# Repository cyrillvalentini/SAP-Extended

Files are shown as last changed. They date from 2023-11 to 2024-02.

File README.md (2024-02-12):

# SAP-Extended
Simple-As-Possible Computer based on [Ben Eaters video series](https://www.youtube.com/watch?v=HyznrdDSSGM&list=PLowKtXNTBypGqImE405J2565dvjafglHU&pp=iAQB).
## Project
As part of my matura project, I planned and build an 8-Bit computer based around the design from Ben Eater. This repository contains the schematics, design files and instructions for the computer.
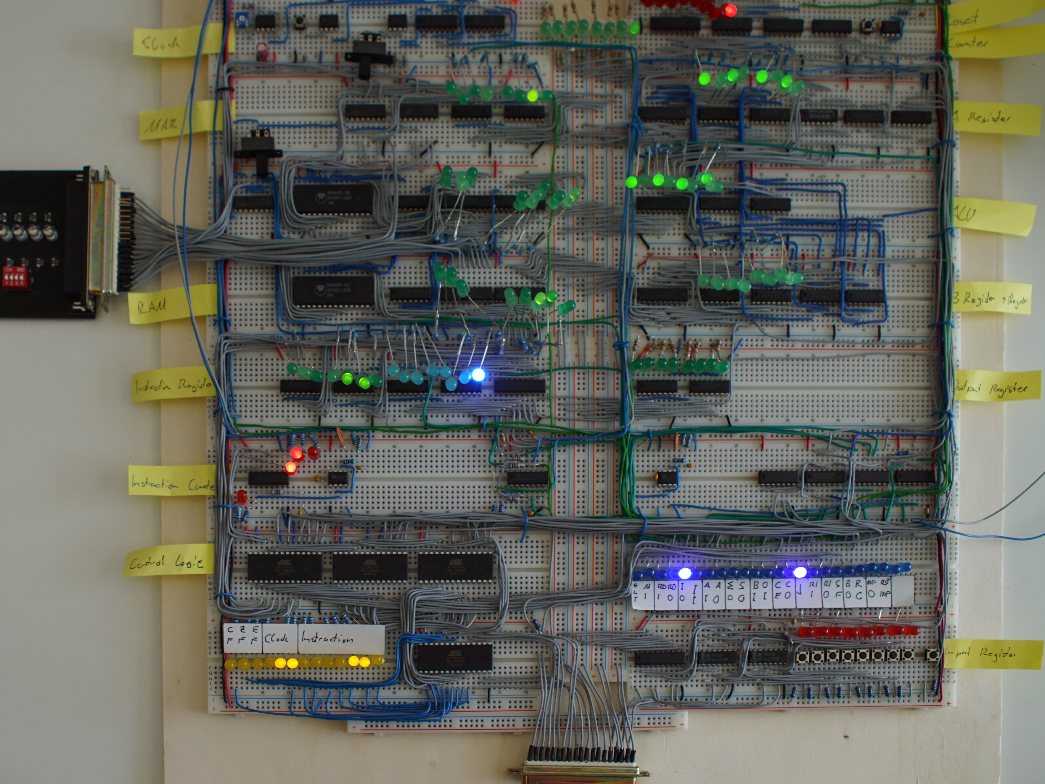
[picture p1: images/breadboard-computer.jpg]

## Breadboard-computer
The breadboard variant is heavily inspired by the computer made by Ben Eater. In the first phase I build computer, which is functionally similar to his design, while occasionally using different parts which were either already on hand or made the process of expanding easier in the future. After a successful test run, I started to expand the design. To allow for longer programs I expanded the RAM to allow 8-Bit addresses and 7-Bit instructions. This allows for a maximum length of 256 instructions. In order to make these changes different modules had to be expanded as well. The other major difference is the expansion port, which allows expansion cards to be created for the computer. The signals are handled by an additional EEPROM-chip within the control logic.

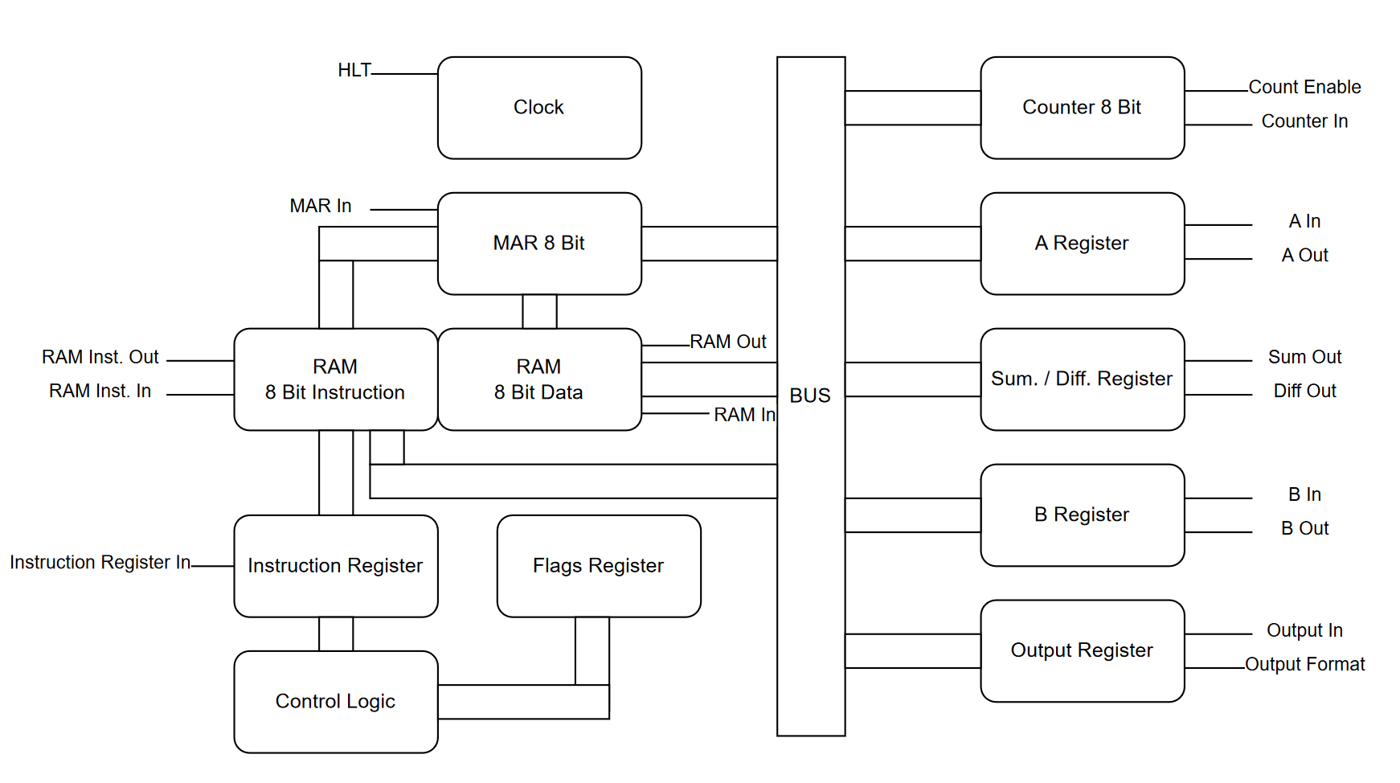
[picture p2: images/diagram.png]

*Simplified diagram of the changes made to the architecture.* 

## Schematics and PCB
After building the breadboard variant, I started working on a PCB version. Being the first larger design, there are some power related issues and some missing filtering components which prevent the computer from running completely. In addition to the breadboard version this design includes a 7-segment display as well as additional power input options. There is an integrated buck converter and an USB Type C port which can supply 5V 3A using PD.

The schematics and PCB were created using KiCad 7.

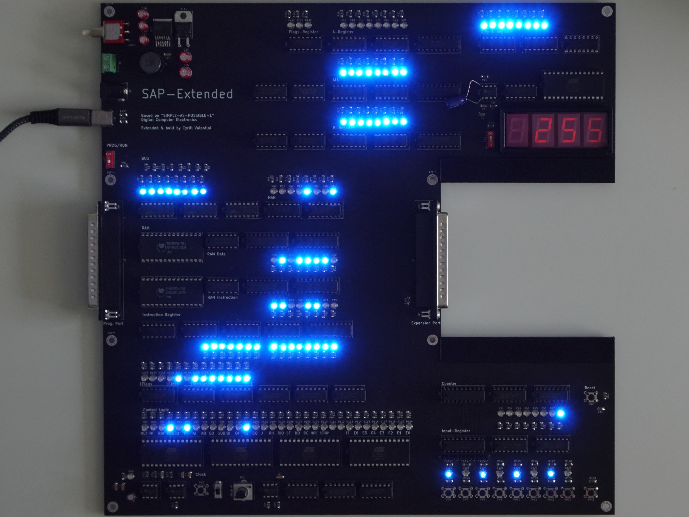
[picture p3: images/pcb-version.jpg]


## Usage
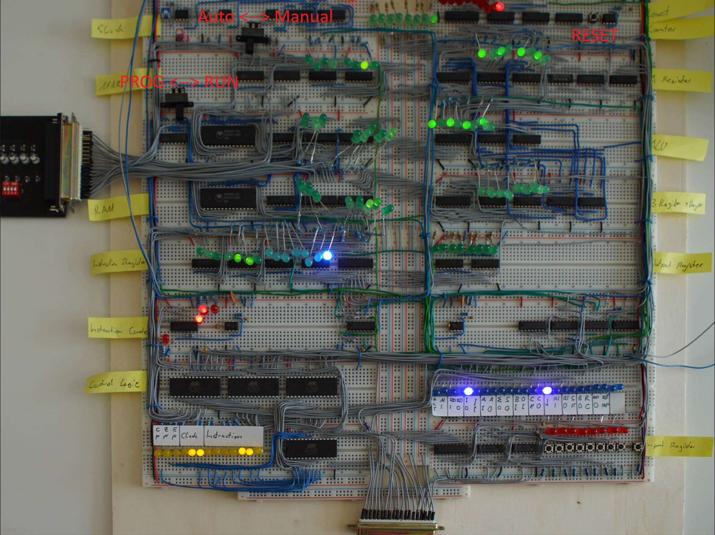
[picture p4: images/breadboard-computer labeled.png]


### Programming the computer
To set the computer to programming mode, the clock switch must first be set to manual. The LED should then stop flashing. It is then advisable to press the RESET button once to clear all registers. To be able to program the computer, the programmer must also be plugged in and the RUN/PROGRAM switch must be set to PROGRAM.

Now the actual programming can begin. First, the desired address must be set; without jump commands, these are iterated through in ascending order. In this case, the first command can be saved in the address 00000001. This is followed by the actual command, which can also be entered using the DIP switches. Finally, if the command requires it, the address to be accessed by the command can be entered under "DATA". Once the entire command has been typed in, the "FLASH" button can be pressed. The command should then be displayed in RAM. It is important that the address 00000000 is empty and is not used, as the computer does not always read in the first command after resetting.

### Examples
<center>

| RAM-address| adding two numbers | show input in output-register |
|---|---|---|
| 0000 0001  | 0000 0001 0000 1000 (LDA) | 0000 1010 0000 0000 (INA) |
| 0000 0010  | 0000 0011 0001 0000 (ADD) | 0000 0101 0000 0000 (OUT) |
| 0000 0011  | 0000 0101 0000 0000 (OUT) | 0000 0110 0000 0001 (JMP) |
| 0000 0100  | 0000 1100 0000 0000 (HLT) | |
| ... | | |
| 0000 0100  | 0000 0000 0000 0011 (3) | |
| ... | | |
| 0000 0100  | 0000 0000 0000 0001 (1) | |

</center>

### Run a program
To start the program, the switch must be set to RUN. As soon as this has been done, the program can be started either manually by using the button or by switching to automatic mode. For the I/O, it should be noted that the switch next to the display can be used to switch the decimal output between unsigned binary and two's complement. In addition, the input register deletes its contents after use or can be deleted manually using the button next to it. The commands can be found [here](https://github.com/cyrillvalentini/SAP-Extended/blob/main/instructions.pdf)
## Microcode
The control logic is build using AT28C64B parallel EEPROMs, which need to be programmed. The binary file was created using the [txt2bin.py](https://github.com/cyrillvalentini/SAP-Extended/blob/main/microcode/txt2bin.py) python script. The microcode can conveniently be changed as a text file and converted back into a binary image.

The microcode can be flashed to the EEPROMs using crmaykish's [Arduino Mega EEPROM programmer](https://github.com/crmaykish/AT28C-EEPROM-Programmer-Arduino). After hooking everything up as described in the documentation, the EEPROMs can be flashed with their corresponding firmware using following command:

`python.exe .\at28c_programmer.py -d <port> -o 0 -f <microcode.bin> -l 8192 -w`

## Programming port
The modular programming interface allows to use different programmers to load the program into RAM. As of now, there is only a manual programmer that can be used, automatic variants are planned. The interface connects the programmer with a set of multiplexer, which can be controlled using the corresponding switch. By switching to programming mode, the RAM-address as well as the data pins are connected with the pins in the port, which can be accessed by the programmer. There is an additional flash-signal which is hooked up to the write input of the RAM-chips. The full specs of the pins can be found [here](https://github.com/cyrillvalentini/SAP-Extended/blob/main/expansions/programming-port%20specification.pdf).

Note that for entering the programming mode successfully the clock must be set to manual in order to function correctly.

## Expansions
To allow for future expansion both versions of the computer have an expansion port controlled by a dedicated EEPROM within the control logic. There are 16 individual instructions present in the microcode, which can be used to interact with the expansion. The full specifications can be found [here](https://github.com/cyrillvalentini/SAP-Extended/blob/main/expansions/expansion-port%20specification.pdf).

### 8x8 LED-matrix
As of now, the LED-matrix expansion is still in a prototyping phase. Once finished this expansion will allow to display simple graphics which can be copied row by row from either the RAM or the A-register. Combined with the input buttons this will allow the development of simple games, which can be run on the computer. 

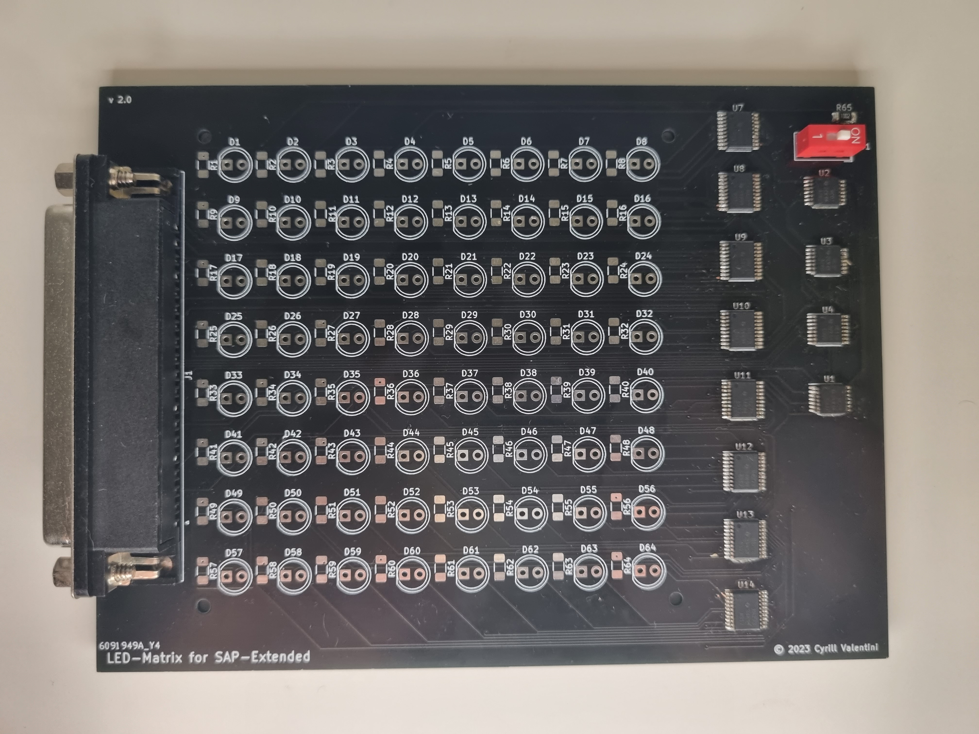
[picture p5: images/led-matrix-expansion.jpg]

*Unfinished prototype of the 8x8 led-matrix*

### Planed expansions
- ALU expansion to allow for additional operations (e.g. logic operations)
- LCD character display
- Automatic programmer

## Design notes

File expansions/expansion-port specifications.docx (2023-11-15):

# Pin allocation expansion-port

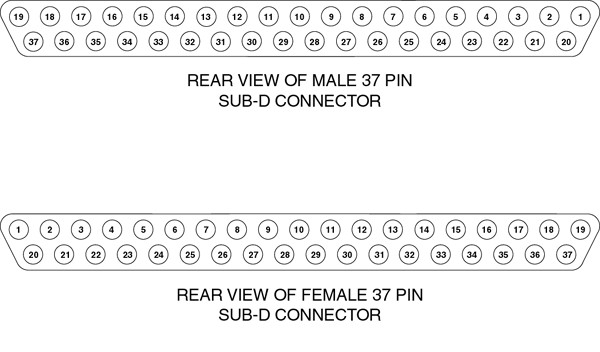
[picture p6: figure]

Image 1 https://forum.dcs.world/topic/184909-a-10c-fmscdu-from-ebay/

Pin: | Allocation: | | Pin: | Allocation
1 | RESET | | 20 | -
2 | FLAG | | 21 | -
3 | CLK | | 22 | -
4 | E7 | | 23 | -
5 | E6 | | 24 | -
6 | E5 | | 25 | -
7 | E4 | | 26 | -
8 | E3 | | 27 | -
9 | E2 | | 28 | -
10 | E1 | | 29 | -
11 | E0 | | 30 | -
12 | BUS7 | | 31 | -
13 | BUS6 | | 32 | -
14 | BUS5 | | 33 | -
15 | BUS4 | | 34 | VCC
16 | BUS3 | | 35 | VCC
17 | BUS2 | | 36 | GND
18 | BUS1 | | 37 | GND
19 | BUS0

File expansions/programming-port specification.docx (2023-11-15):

# Pin allocation programming-port


Image 1 https://forum.dcs.world/topic/184909-a-10c-fmscdu-from-ebay/

Pin: | Allocation: | | Pin: | Allocation:
1 | - | | 20 | RD0
2 | - | | 21 | RD1
3 | - | | 22 | RD2
4 | - | | 23 | RD3
5 | - | | 24 | RD4
6 | - | | 25 | RD5
7 | - | | 26 | RD6
8 | - | | 27 | RD7
9 | - | | 28 | RI0
10 | - | | 29 | RI1
11 | ADR0 | | 30 | RI2
12 | ADR1 | | 31 | RI3
13 | ADR2 | | 32 | RI4
14 | ADR3 | | 33 | RI5
15 | ADR4 | | 34 | RI6
16 | ADR5 | | 35 | RI7
17 | ADR6 | | 36 | WE
18 | ADR7 | | 37 | GND
19 | VCC

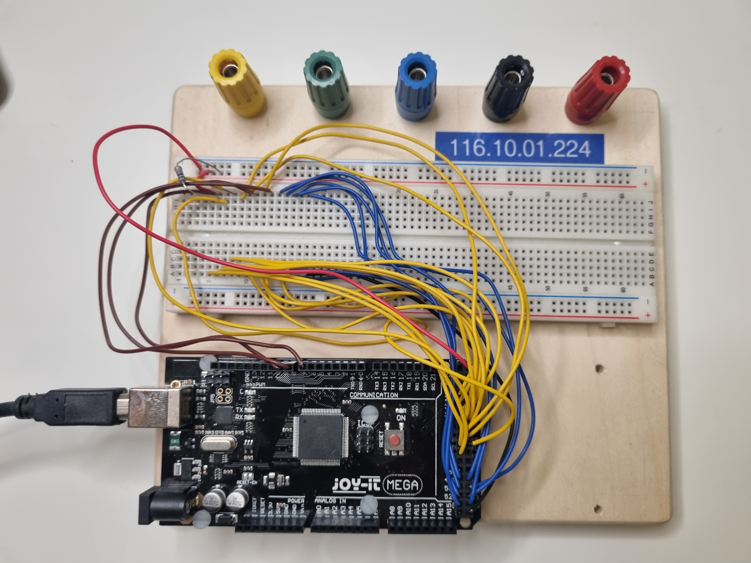
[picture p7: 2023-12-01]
images/arduino-mega-programmer.jpg

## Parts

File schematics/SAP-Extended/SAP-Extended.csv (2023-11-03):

Source: | C:\Users\Cyril\OneDrive - Gymnasium Lerbermatt\MA\SAP-Extended\SAP-Extended\SAP-Extended.kicad_sch
Date: | 19.07.2023 22:45:41
Tool: | Eeschema 7.0.5
Generator: | C:\Program Files\KiCad\7.0\bin\scripting\plugins/bom_csv_grouped_by_value_with_fp.py
Component Count: | 399
Ref | Qnty | Value | Cmp name | Footprint | Description | Vendor | DNP
C1, C2, C16 | 3 | 0.01 uF | C_Small | Capacitor_SMD:C_1206_3216Metric_Pad1.33x1.80mm_HandSolder | Unpolarized capacitor, small symbol
C3, C4, C6 | 3 | 0.1µF | C | Capacitor_SMD:C_1206_3216Metric_Pad1.33x1.80mm_HandSolder | Unpolarized capacitor
C5, C7, C8 | 3 | 0.01µF | C | Capacitor_SMD:C_1206_3216Metric_Pad1.33x1.80mm_HandSolder | Unpolarized capacitor
C9 | 1 | 1µF | CP1-Device | Capacitor_THT:CP_Radial_D5.0mm_P2.00mm
C10, C11, C12 | 3 | 15 µF/50V | C_Polarized_Small | Capacitor_THT:CP_Radial_D5.0mm_P2.00mm | Polarized capacitor, small symbol
C13 | 1 | 0.01 µF | C_Small | Capacitor_SMD:C_1206_3216Metric | Unpolarized capacitor, small symbol
C14 | 1 | 180 µF / 16 V | C_Polarized_Small | Capacitor_THT:CP_Radial_D6.3mm_P2.50mm | Polarized capacitor, small symbol
C15 | 1 | 180 µF/ 16V | C_Polarized_Small | Capacitor_THT:CP_Radial_D6.3mm_P2.50mm | Polarized capacitor, small symbol
D1, D2, D3, D4, D5, D6, D7, D8, D49, D82, D90, D91, D92, D93, D94, D95, D96, D97, D98, D99, D100, D101, D102, D103, D104, D105, D106, D107, D108, D109, D110, D111, D112, D113, D114, D115, D116, D117, D118, D119, D120 | 41 | LED | LED | LED_THT:LED_D3.0mm | Light emitting diode
D9 | 1 | B_0 | LED | LED_THT:LED_D3.0mm | Light emitting diode
D10 | 1 | B_1 | LED | LED_THT:LED_D3.0mm | Light emitting diode
D11 | 1 | B_2 | LED | LED_THT:LED_D3.0mm | Light emitting diode
D12 | 1 | B_3 | LED | LED_THT:LED_D3.0mm | Light emitting diode
D13 | 1 | B_4 | LED | LED_THT:LED_D3.0mm | Light emitting diode
D14 | 1 | B_5 | LED | LED_THT:LED_D3.0mm | Light emitting diode
D15 | 1 | B_6 | LED | LED_THT:LED_D3.0mm | Light emitting diode
D16 | 1 | B_7 | LED | LED_THT:LED_D3.0mm | Light emitting diode
D17 | 1 | A_7 | LED | LED_THT:LED_D3.0mm | Light emitting diode
D18 | 1 | A_6 | LED | LED_THT:LED_D3.0mm | Light emitting diode
D19 | 1 | A_5 | LED | LED_THT:LED_D3.0mm | Light emitting diode
D20 | 1 | A_4 | LED | LED_THT:LED_D3.0mm | Light emitting diode
D21 | 1 | A_3 | LED | LED_THT:LED_D3.0mm | Light emitting diode
D22 | 1 | A_2 | LED | LED_THT:LED_D3.0mm | Light emitting diode
D23 | 1 | A_1 | LED | LED_THT:LED_D3.0mm | Light emitting diode
D24 | 1 | A_0 | LED | LED_THT:LED_D3.0mm | Light emitting diode
D25 | 1 | S_7 | LED | LED_THT:LED_D3.0mm | Light emitting diode
D26 | 1 | S_6 | LED | LED_THT:LED_D3.0mm | Light emitting diode
D27 | 1 | S_5 | LED | LED_THT:LED_D3.0mm | Light emitting diode
D28 | 1 | S_4 | LED | LED_THT:LED_D3.0mm | Light emitting diode
D29 | 1 | S_3 | LED | LED_THT:LED_D3.0mm | Light emitting diode
D30 | 1 | S_2 | LED | LED_THT:LED_D3.0mm | Light emitting diode
D31 | 1 | S_1 | LED | LED_THT:LED_D3.0mm | Light emitting diode
D32 | 1 | S_0 | LED | LED_THT:LED_D3.0mm | Light emitting diode
D33 | 1 | O_7 | LED | LED_THT:LED_D3.0mm | Light emitting diode
D34 | 1 | O_6 | LED | LED_THT:LED_D3.0mm | Light emitting diode
D35 | 1 | O_5 | LED | LED_THT:LED_D3.0mm | Light emitting diode
D36 | 1 | O_4 | LED | LED_THT:LED_D3.0mm | Light emitting diode
D37 | 1 | O_3 | LED | LED_THT:LED_D3.0mm | Light emitting diode
D38 | 1 | O_2 | LED | LED_THT:LED_D3.0mm | Light emitting diode
D39 | 1 | O_1 | LED | LED_THT:LED_D3.0mm | Light emitting diode
D40 | 1 | O_0 | LED | LED_THT:LED_D3.0mm | Light emitting diode
D41 | 1 | C_7 | LED | LED_THT:LED_D3.0mm | Light emitting diode
D42 | 1 | C_6 | LED | LED_THT:LED_D3.0mm | Light emitting diode
D43 | 1 | C_5 | LED | LED_THT:LED_D3.0mm | Light emitting diode
D44 | 1 | C_4 | LED | LED_THT:LED_D3.0mm | Light emitting diode
D45 | 1 | C_3 | LED | LED_THT:LED_D3.0mm | Light emitting diode
D46 | 1 | C_2 | LED | LED_THT:LED_D3.0mm | Light emitting diode
D47 | 1 | C_1 | LED | LED_THT:LED_D3.0mm | Light emitting diode
D48 | 1 | C_0 | LED | LED_THT:LED_D3.0mm | Light emitting diode
D50 | 1 | M_7 | LED | LED_THT:LED_D3.0mm | Light emitting diode
D51 | 1 | M_6 | LED | LED_THT:LED_D3.0mm | Light emitting diode
D52 | 1 | M_5 | LED | LED_THT:LED_D3.0mm | Light emitting diode
D53 | 1 | M_4 | LED | LED_THT:LED_D3.0mm | Light emitting diode
D54 | 1 | M_3 | LED | LED_THT:LED_D3.0mm | Light emitting diode
D55 | 1 | M_2 | LED | LED_THT:LED_D3.0mm | Light emitting diode
D56 | 1 | M_1 | LED | LED_THT:LED_D3.0mm | Light emitting diode
D57 | 1 | M_0 | LED | LED_THT:LED_D3.0mm | Light emitting diode
D58 | 1 | RD_0 | LED | LED_THT:LED_D3.0mm | Light emitting diode
D59 | 1 | RD_1 | LED | LED_THT:LED_D3.0mm | Light emitting diode
D60 | 1 | RD_2 | LED | LED_THT:LED_D3.0mm | Light emitting diode
D61 | 1 | RD_3 | LED | LED_THT:LED_D3.0mm | Light emitting diode
D62 | 1 | RD_4 | LED | LED_THT:LED_D3.0mm | Light emitting diode
D63 | 1 | RD_5 | LED | LED_THT:LED_D3.0mm | Light emitting diode
D64 | 1 | RD_6 | LED | LED_THT:LED_D3.0mm | Light emitting diode
D65 | 1 | RD_7 | LED | LED_THT:LED_D3.0mm | Light emitting diode
D66 | 1 | RI_7 | LED | LED_THT:LED_D3.0mm | Light emitting diode
D67 | 1 | RI_6 | LED | LED_THT:LED_D3.0mm | Light emitting diode
D68 | 1 | RI_5 | LED | LED_THT:LED_D3.0mm | Light emitting diode
D69 | 1 | RI_4 | LED | LED_THT:LED_D3.0mm | Light emitting diode
D70 | 1 | RI_3 | LED | LED_THT:LED_D3.0mm | Light emitting diode
D71 | 1 | RI_2 | LED | LED_THT:LED_D3.0mm | Light emitting diode
D72 | 1 | RI_1 | LED | LED_THT:LED_D3.0mm | Light emitting diode
D73 | 1 | RI_0 | LED | LED_THT:LED_D3.0mm | Light emitting diode
D74 | 1 | IRD_7 | LED | LED_THT:LED_D3.0mm | Light emitting diode
D75 | 1 | IRD_6 | LED | LED_THT:LED_D3.0mm | Light emitting diode
D76 | 1 | IRD_5 | LED | LED_THT:LED_D3.0mm | Light emitting diode
D77 | 1 | IRD_4 | LED | LED_THT:LED_D3.0mm | Light emitting diode
D78 | 1 | IRD_3 | LED | LED_THT:LED_D3.0mm | Light emitting diode
D79 | 1 | IRD_2 | LED | LED_THT:LED_D3.0mm | Light emitting diode
D80 | 1 | IRD_1 | LED | LED_THT:LED_D3.0mm | Light emitting diode
D81 | 1 | IRD_0 | LED | LED_THT:LED_D3.0mm | Light emitting diode
D83 | 1 | IRI_6 | LED | LED_THT:LED_D3.0mm | Light emitting diode
D84 | 1 | IRI_5 | LED | LED_THT:LED_D3.0mm | Light emitting diode
D85 | 1 | IRI_4 | LED | LED_THT:LED_D3.0mm | Light emitting diode
D86 | 1 | IRI_3 | LED | LED_THT:LED_D3.0mm | Light emitting diode
D87 | 1 | IRI_2 | LED | LED_THT:LED_D3.0mm | Light emitting diode
D88 | 1 | IRI_1 | LED | LED_THT:LED_D3.0mm | Light emitting diode
D89 | 1 | IRI_0 | LED | LED_THT:LED_D3.0mm | Light emitting diode
D121 | 1 | STPS745 | D_Schottky | Package_TO_SOT_THT:TO-220-2_Horizontal_TabDown | Schottky diode
D122 | 1 | IN_7 | LED | LED_THT:LED_D3.0mm | Light emitting diode
D123 | 1 | IN_6 | LED | LED_THT:LED_D3.0mm | Light emitting diode
D124 | 1 | IN_5 | LED | LED_THT:LED_D3.0mm | Light emitting diode
D125 | 1 | IN_4 | LED | LED_THT:LED_D3.0mm | Light emitting diode
D126 | 1 | IN_3 | LED | LED_THT:LED_D3.0mm | Light emitting diode
D127 | 1 | IN_2 | LED | LED_THT:LED_D3.0mm | Light emitting diode
D128 | 1 | IN_1 | LED | LED_THT:LED_D3.0mm | Light emitting diode
D129 | 1 | IN_0 | LED | LED_THT:LED_D3.0mm | Light emitting diode
D130 | 1 | CF | LED |  | Light emitting diode
D131 | 1 | ZF | LED |  | Light emitting diode
D132 | 1 | EF | LED |  | Light emitting diode
J1 | 1 | Screw_Terminal_01x02 | Screw_Terminal_01x02 | TerminalBlock_Phoenix:TerminalBlock_Phoenix_MKDS-1,5-2_1x02_P5.00mm_Horizontal | Generic screw terminal, single row, 01x02, script generated (kicad-library-utils/schlib/autogen/connector/)
J2, J3 | 2 | DC37_Plug | DC37_Plug | Connector_Dsub:DSUB-37_Male_Horizontal_P2.77x2.84mm_EdgePinOffset4.94mm_Housed_MountingHolesOffset7.48mm | 37-pin male plug pin D-SUB connector
J4 | 1 | USB_C_Receptacle_PowerOnly_6P | USB_C_Receptacle_PowerOnly_6P | Connector_USB:USB_C_Receptacle_GCT_USB4085 | USB Power-Only 6P Type-C Receptacle connector
J5 | 1 | Barrel_Jack | Barrel_Jack | Connector_BarrelJack:BarrelJack_GCT_DCJ200-10-A_Horizontal | DC Barrel Jack
L1 | 1 | 22 µH | L | Inductor_THT:L_Radial_D12.0mm_P10.00mm_Neosid_SD12_style1 | Inductor
R1, R2, R3, R4, R5, R6, R7, R8, R49, R60, R92, R140, R149, R150, R151, R152, R153, R154, R155, R156, R159 | 21 | 10K | R | Resistor_SMD:R_1206_3216Metric_Pad1.30x1.75mm_HandSolder | Resistor
R9, R10, R11, R12, R13, R14, R15, R16, R17, R18, R19, R20, R21, R22, R23, R24, R25, R26, R27, R28, R29, R30, R31, R32, R33, R34, R35, R36, R37, R38, R39, R40, R41, R42, R43, R44, R45, R46, R47, R48, R52, R53, R54, R55, R56, R57, R58, R59, R67, R68, R69, R70, R71, R72, R73, R74, R75, R76, R77, R78, R79, R80, R81, R82, R83, R84, R85, R86, R87, R88, R89, R90, R91, R93, R94, R95, R96, R97, R98, R99, R100, R101, R102, R103, R104, R105, R106, R107, R108, R109, R110, R111, R112, R113, R114, R115, R116, R117, R118, R119, R120, R121, R122, R123, R124, R125, R126, R127, R128, R129, R130, R131, R132, R133, R134, R135, R136, R137, R138, R139, R141, R142, R143, R144, R145, R146, R147, R148 | 128 | 470 | R | Resistor_SMD:R_1206_3216Metric_Pad1.30x1.75mm_HandSolder | Resistor
R50 | 1 | 100K | R | Resistor_SMD:R_1206_3216Metric_Pad1.30x1.75mm_HandSolder | Resistor
R51, R61, R62, R66 | 4 | 1K | R | Resistor_SMD:R_1206_3216Metric_Pad1.30x1.75mm_HandSolder | Resistor
R63 | 1 | 1M | R | Resistor_SMD:R_1206_3216Metric_Pad1.30x1.75mm_HandSolder | Resistor
R64, R65 | 2 | 1K | R | Resistor_THT:R_Axial_DIN0207_L6.3mm_D2.5mm_P7.62mm_Horizontal | Resistor
R157, R158 | 2 | 5.1K | R | Resistor_SMD:R_1206_3216Metric_Pad1.30x1.75mm_HandSolder | Resistor
R160, R161, R162 | 3 | 470 | R |  | Resistor
RV1 | 1 | 1M | POT-8bit-computer-rescue | Potentiometer_THT:Potentiometer_ACP_CA6-H2,5_Horizontal
SW1, SW5 | 2 | SW_DIP_x01 | SW_DIP_x01 | Button_Switch_THT:SW_DIP_SPSTx01_Slide_9.78x4.72mm_W7.62mm_P2.54mm | 1x DIP Switch, Single Pole Single Throw (SPST) switch, small symbol
SW2, SW15 | 2 | SW_Push | SW_Push | Button_Switch_THT:SW_PUSH_6mm | Push button switch, generic, two pins
SW3 | 1 | SW_Push | SW_Push-8bit-computer-rescue | Button_Switch_THT:SW_PUSH_6mm_H5mm
SW4 | 1 | SW_SPDT | SW_SPDT-8bit-computer-rescue | Button_Switch_THT:SW_Slide_1P2T_CK_OS102011MS2Q
SW6, SW7, SW8, SW9, SW10, SW11, SW12, SW13 | 8 | SW | SW_Push | Button_Switch_THT:SW_PUSH_6mm | Push button switch, generic, two pins
SW14 | 1 | 700SP7B20M6QE | 700SP7B20M6QE | Footprints:E-Switch-700SP7B20M6QE-0-0-MFG | 700SP7B20M6QE
U1, U4, U7, U24, U38, U39, U40, U41, U49, U62 | 10 | 74HC245 | 74HC245 | Package_DIP:DIP-20_W7.62mm_Socket | Octal BUS Transceivers, 3-State outputs
U2, U3, U5, U6, U12, U13, U32, U33, U64 | 9 | 74LS195 | 74LS195 | Package_DIP:DIP-16_W7.62mm_Socket | Shift Register 4-bit, parallel
U8, U9 | 2 | 74LS283 | 74LS283 | Package_DIP:DIP-16_W7.62mm_Socket | 4-bit full Adder
U10, U11 | 2 | 74LS86 | 74LS86 | Package_DIP:DIP-14_W7.62mm_Socket | Quad 2-input XOR
U14, U15, U16, U17 | 4 | D168K | D168K | Display_7Segment:D1X8K | One digit 7 segment ultra bright red LED, low current, common cathode
U18 | 1 | AT28C64B-15PU | AT28C64B-15PU | Package_DIP:DIP-28_W15.24mm_Socket | AT28C64B-15PU
U19 | 1 | 74LS139 | 74LS139 |  | Dual Decoder 1 of 4, Active low outputs
U20 | 1 | LM555xN | LM555xN | Package_DIP:DIP-8_W7.62mm_Socket | Timer, 555 compatible, PDIP-8
U21 | 1 | 74LS107 | 74LS107 | Package_DIP:DIP-14_W7.62mm_Socket | Dual JK Flip-Flop, reset
U22, U23, U50 | 3 | 74LS161 | 74LS161 | Package_DIP:DIP-16_W7.62mm_Socket | Synchronous 4-bit programmable binary Counter
U25, U26 | 2 | 74HC04 | 74HC04 | Package_DIP:DIP-14_W7.62mm_Socket | Hex Inverter
U27, U28, U29 | 3 | LM555 | LM555-8bit-computer-rescue | Package_DIP:DIP-8_W7.62mm_Socket
U30, U43, U56 | 3 | 74LS32 | 74LS32 | Package_DIP:DIP-14_W7.62mm_Socket | Quad 2-input OR
U31, U57, U58, U65 | 4 | 74LS08 | 74LS08 | Package_DIP:DIP-14_W7.62mm_Socket | Quad And2
U34, U35, U44 | 3 | 74LS157 | 74LS157 | Package_DIP:DIP-16_W7.62mm_Socket | Quad 2 to 1 line Multiplexer
U36 | 1 | RAM_DATA | AS6C6264-55PCN | Package_DIP:DIP-28_W15.24mm_Socket | AS6C6264-55PCN
U37 | 1 | RAM_INSTUCTION | AS6C6264-55PCN | Package_DIP:DIP-28_W15.24mm_Socket | AS6C6264-55PCN
U42, U55, U59 | 3 | 74LS04 | 74LS04 | Package_DIP:DIP-14_W7.62mm_Socket | Hex Inverter
U45 | 1 | IR_2 | 74LS195 | Package_DIP:DIP-16_W7.62mm_Socket | Shift Register 4-bit, parallel
U46 | 1 | IR_1 | 74LS195 | Package_DIP:DIP-16_W7.62mm_Socket | Shift Register 4-bit, parallel
U47 | 1 | DR_2 | 74LS195 | Package_DIP:DIP-16_W7.62mm_Socket | Shift Register 4-bit, parallel
U48 | 1 | DR_1 | 74LS195 | Package_DIP:DIP-16_W7.62mm_Socket | Shift Register 4-bit, parallel
U51, U52, U53, U54 | 4 | AT28C64B | AT28C64B-15PU | Package_DIP:DIP-28_W15.24mm_Socket | AT28C64B-15PU
U60, U61 | 2 | ~ | SN74LS279 | Package_DIP:DIP-16_W7.62mm_Socket
U63 | 1 | LM2678 | LM22678TJ-5 | Package_TO_SOT_SMD:TO-263-7_TabPin8 | 5A Step-Down Switching Voltage Regulater, 4.5-42V Input, 5V Output, 500kHz Switching Frequency, TO-263
U66 | 1 | 74LS02 | 74LS02 | Package_DIP:DIP-14_W7.62mm_Socket | quad 2-input NOR gate
U67 | 1 | 74LS139 | 74LS139 | Package_DIP:DIP-16_W7.62mm_Socket | Dual Decoder 1 of 4, Active low outputs

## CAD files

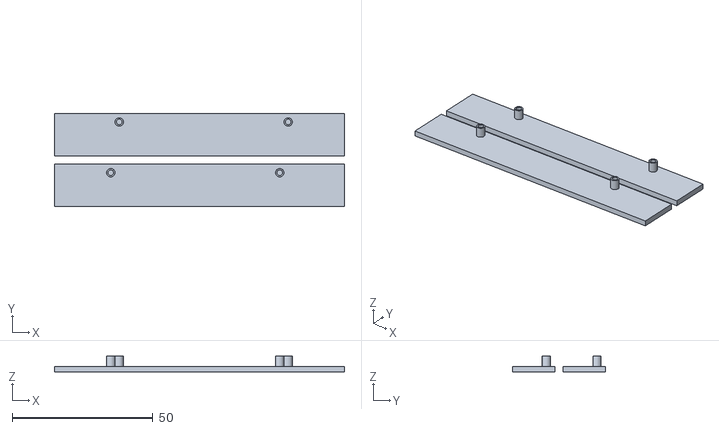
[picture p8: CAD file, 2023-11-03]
3d-models/8-Bit Computer Rails v3 top.stl
103.0 x 33.0 x 5.60

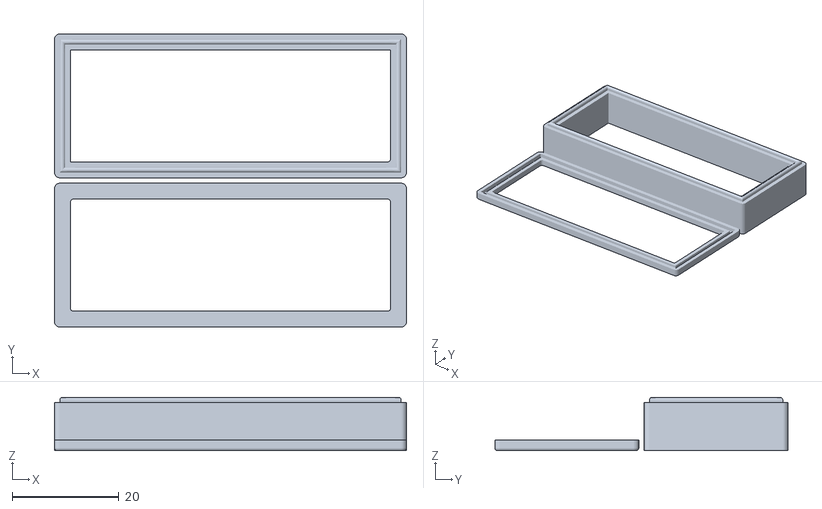
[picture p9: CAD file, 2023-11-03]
3d-models/7-Segment Cover v1.stl
66.0 x 55.0 x 10.0

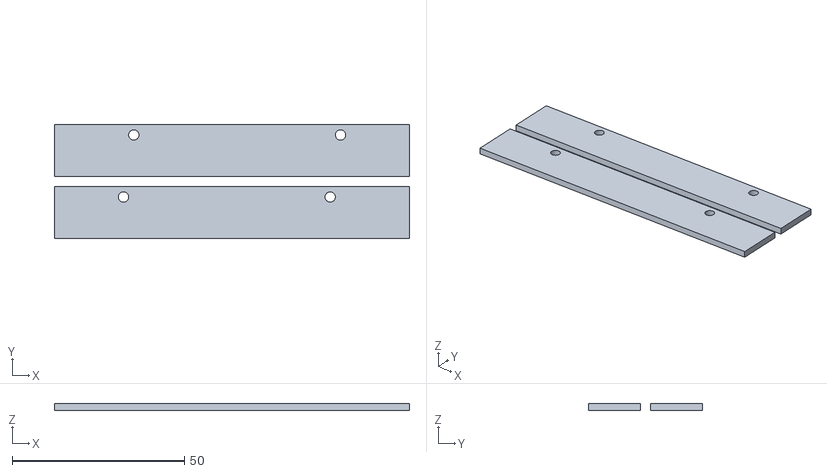
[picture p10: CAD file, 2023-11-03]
3d-models/8-Bit Computer Rails v3 bottom.stl
103.0 x 33.0 x 2.00

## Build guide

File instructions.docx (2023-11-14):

Code: | Instruction: | Signals: | Description:

Main instructions:
xxxxxxxx | FETCH | 1 CO, MI 2 RDO, II, CE | Fetch-Cycle, gets executed for every instruction.
00000001 | LDA | 3 IO, MI 4 RDO, AI 5 RST | Byte gets copied to A-register.
00000010 | LDB | 3, IO, MI 4 RDO, BI 5 RST | Byte gets copied to B-register.
00000011 | ADD | 3 IO, MI 4 RDO, BI 5 EO, AI, SF 6 RST | Byte from A-register gets added to byte in A-register.
00000100 | SUB | 3 IO, MI 4 RDO, BI 5 SO, AI, SF 6 RST | Byte from A-register gets subtracted to byte in A-register.
00000101 | OUT | 3 AO, OI 4 RST | Byte gets copied from the A-register tot he output-register.
00000110 | JMP | 3 IO, J 4 RST | Jumps to given RAM-adress.
00000111 | JC | 3 IO, J 4 RST | Jumps to given RAM-adress , if carry-flag is set.
00001000 | JZ | 3 IO, J 4 RST | Jumps to given RAM-adress , if zero-flag is set.
00001001 | JE | 3 IO, J 4 RST | Jumps to given RAM-adress , if expansion-flag is set.
00001010 | INA | 3 INPO, AI 4 RSTINP 5 RST | Byte in input-register gets copied into the A-register
00001011 | INR | 3 IO, MI 4 INPO, RDI 5 RSTINP 6 RST | Byte in input-register gets saved in given RAM-adress
00001100 | HLT | 3 HLT | Halts the computer.
00001101 | SVA | 3 IO, MI 4 RDI, AO 5 RST | Byte in A-register gets saved in given RAM-adress.
00001110 | SVB | 3 IO, MI 4 RDI, BO 5 RST | Byte in B-register gets saved in given RAM-adress.

Instructions for the expansion:
00001111 | RTE0 | 3 IO, MI 4 RDO, E7, E3 5 SF | Byte from RAM gets copied into the expansion.
00010000 | RTE1 | 3 IO, MI 4 RDO, E7, E3, E0 5 SF | Byte from RAM gets copied into the expansion.
00010001 | RTE2 | 3 IO, MI 4 RDO, E7, E3, E1 5 SF | Byte from RAM gets copied into the expansion.
00010010 | RTE3 | 3 IO, MI 4 RDO, E7, E3, E1, E0 5 SF | Byte from RAM gets copied into the expansion.
00010011 | RTE4 | 3 IO, MI 4 RDO, E7, E3, E2 5 SF | Byte from RAM gets copied into the expansion.
00010100 | RTE5 | 3 IO, MI 4 RDO, E7, E3, E2, E0 5 SF | Byte from RAM gets copied into the expansion.
00010101 | RTE6 | 3 IO, MI 4 RDO, E7, E3, E2, E1 5 SF | Byte from RAM gets copied into the expansion.
00010110 | RTE7 | 3 IO, MI 4 RDO, E7, E3, E2, E1, E0 5 SF | Byte from RAM gets copied into the expansion.
00010111 | ETR0 | 3 IO, MI 4 RDI, E7, E4, E3 5 SF | Byte from RAM gets saved in given RAM-adress.
00011000 | ETR1 | 3 IO, MI 4 RDI, E7, E4, E3, E0 5 SF | Byte from RAM gets saved in given RAM-adress.
00011001 | ETR2 | 3 IO, MI 4 RDI, E7, E4, E3, E1 5 SF | Byte from RAM gets saved in given RAM-adress.
00011010 | ETR3 | 3 IO, MI 4 RDI, E7, E4, E3, E1, E0 5 SF | Byte from RAM gets saved in given RAM-adress.
00011011 | ETR4 | 3 IO, MI 4 RDI, E7, E4, E3, E2 5 SF | Byte from RAM gets saved in given RAM-adress.
00011100 | ETR5 | 3 IO, MI 4 RDI, E7, E4, E3, E2, E0 5 SF | Byte from RAM gets saved in given RAM-adress.
00011101 | ETR6 | 3 IO, MI 4 RDI, E7, E4, E3, E2, E1 5 SF | Byte from RAM gets saved in given RAM-adress.
00011110 | ETR7 | 3 IO, MI 4 RDI, E7, E4, E3, E2, E1, E0 5 SF | Byte from RAM gets saved in given RAM-adress.
00011111 | ATE0 | 3 AO, E7 4 SF | Byte from A-register gets copied into the expansion.
00100000 | ATE1 | 3 AO, E7, E0 4 SF | Byte from A-register gets copied into the expansion.
00100001 | ATE2 | 3 AO, E7, E1 4 SF | Byte from A-register gets copied into the expansion.
00100010 | ATE3 | 3 AO, E7, E1, E0 4 SF | Byte from A-register gets copied into the expansion.
00100011 | ATE4 | 3 AO, E7, E2 4 SF | Byte from A-register gets copied into the expansion.
00100100 | ATE5 | 3 AO, E7, E2, E0 4 SF | Byte from A-register gets copied into the expansion..
00100101 | ATE6 | 3 AO, E7, E2, E1 4 SF | Byte from A-register gets copied into the expansion.
00100110 | ATE7 | 3 AO, E7, E2, E1, E0 4 SF | Byte from A-register gets copied into the expansion.
00100111 | ETA0 | 3 AI, E7, E4 4 SF | Byte from the expansion gets copied into the A-Register.
00101000 | ETA1 | 3 AI, E7, E4, E0 4 SF | Byte from the expansion gets copied into the A-Register.
00101001 | ETA2 | 3 AI, E7, E4, E1 4 SF | Byte from the expansion gets copied into the A-Register.
00101010 | ETA3 | 3 AI, E7, E4, E1, E0 4 SF | Byte from the expansion gets copied into the A-Register.
00101011 | ETA4 | 3 AI, E7, E4, E2 4 SF | Byte from the expansion gets copied into the A-Register.
00101100 | ETA5 | 3 AI, E7, E4, E2, E0 4 SF | Byte from the expansion gets copied into the A-Register.
00101101 | ETA6 | 3 AI, E7, E4, E2, E1 4 SF | Byte from the expansion gets copied into the A-Register.
00101110 | ETA7 | 3 AI, E7, E4, E2, E1, E0 4 SF | Byte from the expansion gets copied into the A-Register.

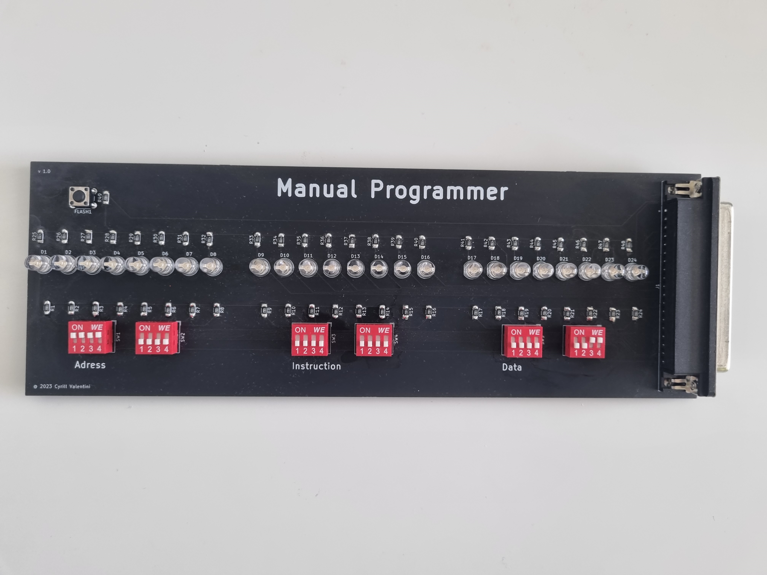
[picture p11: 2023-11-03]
images/manual-programmer.jpg

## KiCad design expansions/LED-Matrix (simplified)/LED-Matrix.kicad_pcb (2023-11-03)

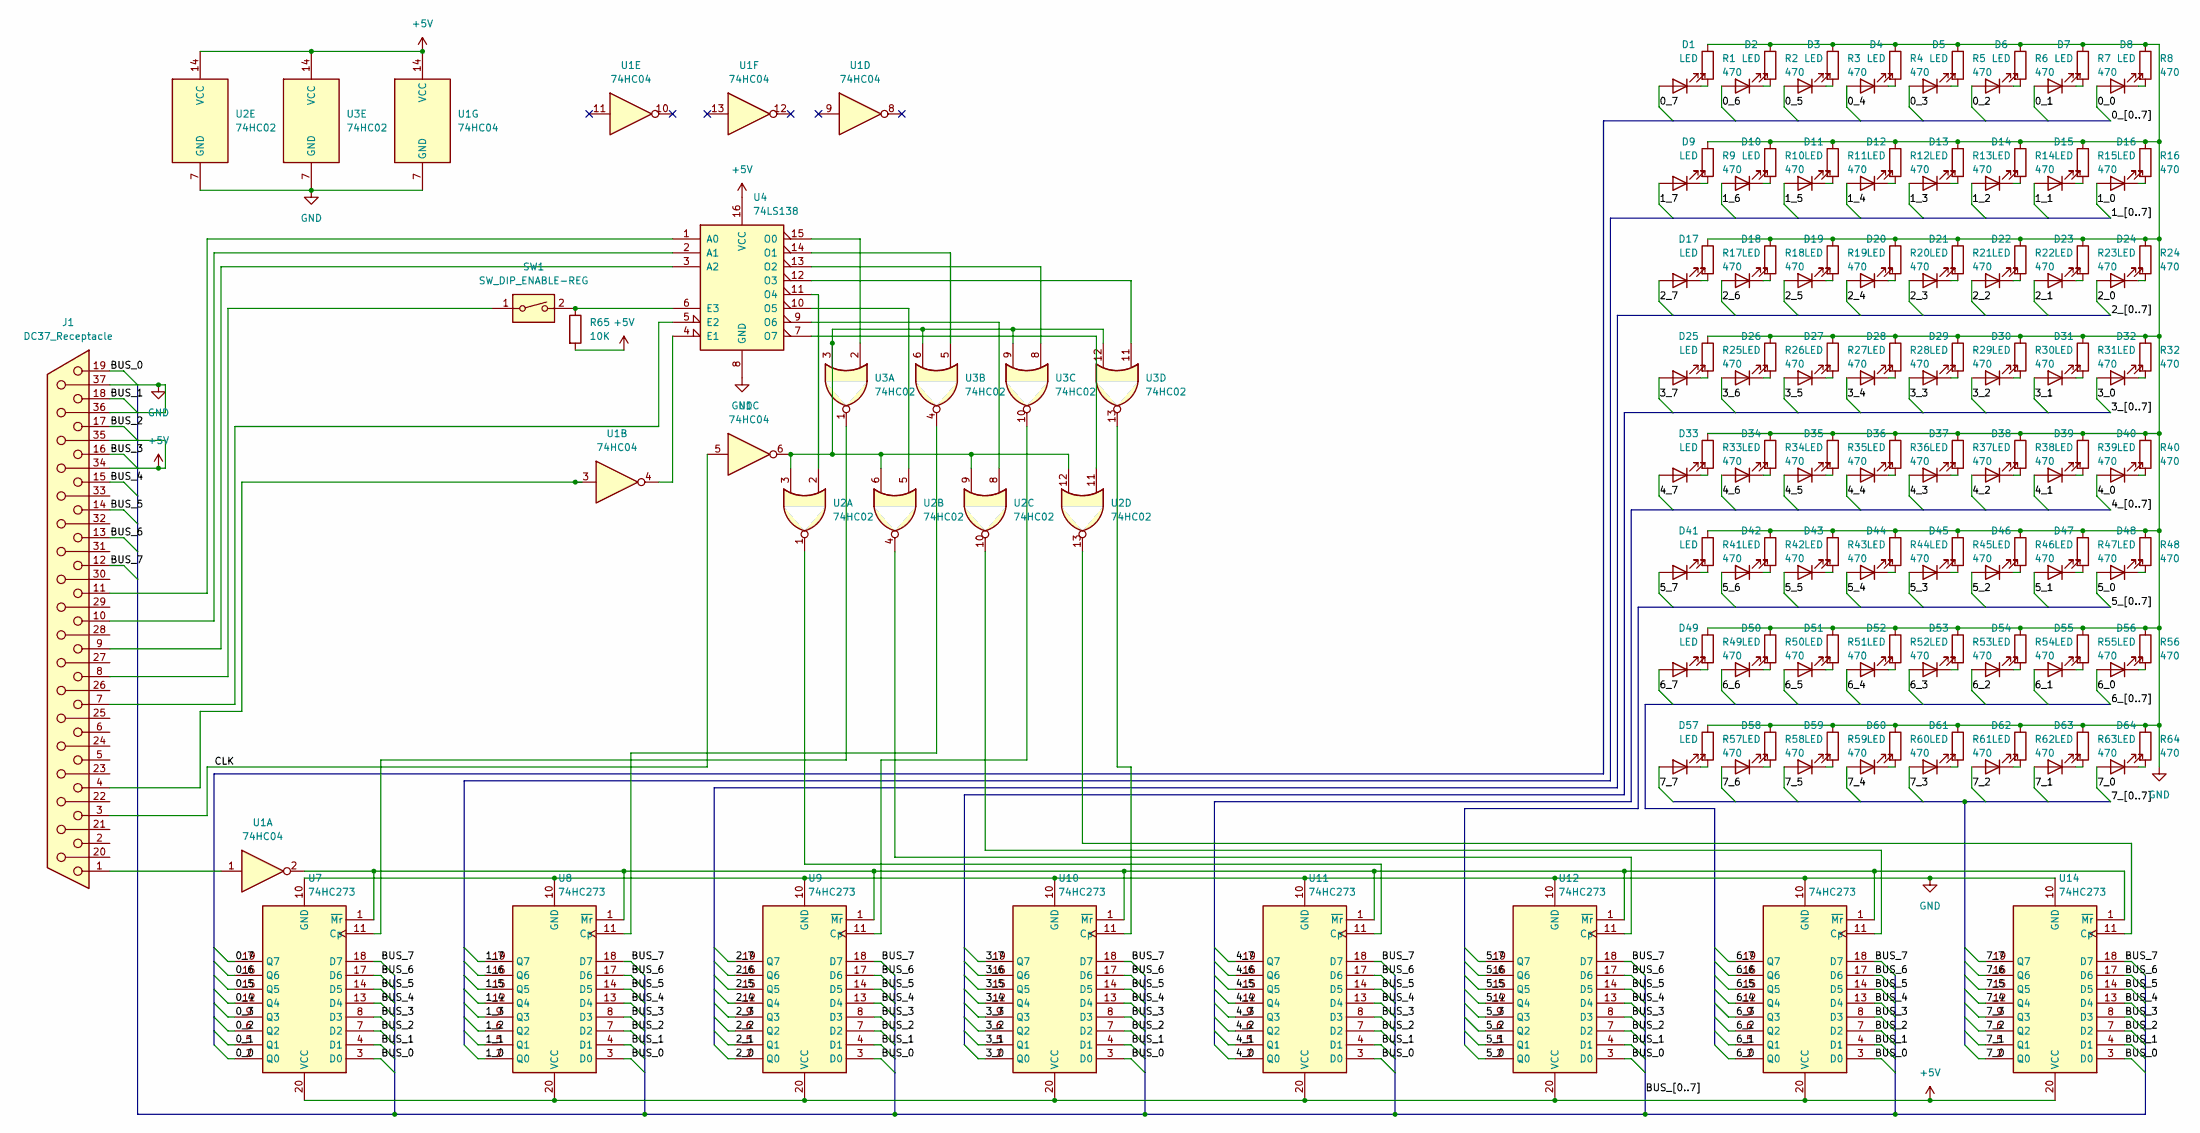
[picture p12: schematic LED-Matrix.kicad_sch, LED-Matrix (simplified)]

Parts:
D1, D2, D3, D4, D5, D6, D7, D8, D9, D10, D11, D12, D13, D14, D15, D16, D17, D18, D19, D20, D21, D22, D23, D24, D25, D26, D27, D28, D29, D30, D31, D32, D33, D34, D35, D36, D37, D38, D39, D40, D41, D42, D43, D44, D45, D46, D47, D48, D49, D50, D51, D52, D53, D54, D55, D56, D57, D58, D59, D60, D61, D62, D63, D64: LED; LED_D5.0mm
J1: DC37_Receptacle; DSUB-37_Female_Horizontal_P2.77x2.84mm_EdgePinOffset9.90mm_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
R1, R2, R3, R4, R5, R6, R7, R8, R9, R10, R11, R12, R13, R14, R15, R16, R17, R18, R19, R20, R21, R22, R23, R24, R25, R26, R27, R28, R29, R30, R31, R32, R33, R34, R35, R36, R37, R38, R39, R40, R41, R42, R43, R44, R45, R46, R47, R48, R49, R50, R51, R52, R53, R54, R55, R56, R57, R58, R59, R60, R61, R62, R63, R64: 470; R_1206_3216Metric_Pad1.30x1.75mm_HandSolder
R65: 10K; R_1206_3216Metric_Pad1.30x1.75mm_HandSolder
SW1: SW_DIP_ENABLE-REG; SW_DIP_SPSTx01_Slide_9.78x4.72mm_W7.62mm_P2.54mm
U1: 74HC04; TSSOP-14_4.4x5mm_P0.65mm
U2, U3: 74HC02; TSSOP-14_4.4x5mm_P0.65mm
U4: 74LS138; TSSOP-16_4.4x5mm_P0.65mm
U7, U8, U9, U10, U11, U12, U13, U14: 74HC273; TSSOP-20_4.4x6.5mm_P0.65mm

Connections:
+5V: J1.34, J1.35, R65.2, U1.14 (VCC), U2.14 (VCC), U3.14 (VCC), U4.16 (VCC), U7.20 (VCC), U8.20 (VCC), U9.20 (VCC), U10.20 (VCC), U11.20 (VCC), U12.20 (VCC), U13.20 (VCC), U14.20 (VCC)
/0_0: D8.2 (A), U7.2 (Q0)
/0_1: D7.2 (A), U7.5 (Q1)
/0_2: D6.2 (A), U7.6 (Q2)
/0_3: D5.2 (A), U7.9 (Q3)
/0_4: D4.2 (A), U7.12 (Q4)
/0_5: D3.2 (A), U7.15 (Q5)
/0_6: D2.2 (A), U7.16 (Q6)
/0_7: D1.2 (A), U7.19 (Q7)
/1_0: D16.2 (A), U8.2 (Q0)
/1_1: D15.2 (A), U8.5 (Q1)
/1_2: D14.2 (A), U8.6 (Q2)
/1_3: D13.2 (A), U8.9 (Q3)
/1_4: D12.2 (A), U8.12 (Q4)
/1_5: D11.2 (A), U8.15 (Q5)
/1_6: D10.2 (A), U8.16 (Q6)
/1_7: D9.2 (A), U8.19 (Q7)
/2_0: D24.2 (A), U9.2 (Q0)
/2_1: D23.2 (A), U9.5 (Q1)
/2_2: D22.2 (A), U9.6 (Q2)
/2_3: D21.2 (A), U9.9 (Q3)
/2_4: D20.2 (A), U9.12 (Q4)
/2_5: D19.2 (A), U9.15 (Q5)
/2_6: D18.2 (A), U9.16 (Q6)
/2_7: D17.2 (A), U9.19 (Q7)
/3_0: D32.2 (A), U10.2 (Q0)
/3_1: D31.2 (A), U10.5 (Q1)
/3_2: D30.2 (A), U10.6 (Q2)
/3_3: D29.2 (A), U10.9 (Q3)
/3_4: D28.2 (A), U10.12 (Q4)
/3_5: D27.2 (A), U10.15 (Q5)
/3_6: D26.2 (A), U10.16 (Q6)
/3_7: D25.2 (A), U10.19 (Q7)
/4_0: D40.2 (A), U11.2 (Q0)
/4_1: D39.2 (A), U11.5 (Q1)
/4_2: D38.2 (A), U11.6 (Q2)
/4_3: D37.2 (A), U11.9 (Q3)
/4_4: D36.2 (A), U11.12 (Q4)
/4_5: D35.2 (A), U11.15 (Q5)
/4_6: D34.2 (A), U11.16 (Q6)
/4_7: D33.2 (A), U11.19 (Q7)
/5_0: D48.2 (A), U12.2 (Q0)
/5_1: D47.2 (A), U12.5 (Q1)
/5_2: D46.2 (A), U12.6 (Q2)
/5_3: D45.2 (A), U12.9 (Q3)
/5_4: D44.2 (A), U12.12 (Q4)
/5_5: D43.2 (A), U12.15 (Q5)
/5_6: D42.2 (A), U12.16 (Q6)
/5_7: D41.2 (A), U12.19 (Q7)
/6_0: D56.2 (A), U13.2 (Q0)
/6_1: D55.2 (A), U13.5 (Q1)
/6_2: D54.2 (A), U13.6 (Q2)
/6_3: D53.2 (A), U13.9 (Q3)
/6_4: D52.2 (A), U13.12 (Q4)
/6_5: D51.2 (A), U13.15 (Q5)
/6_6: D50.2 (A), U13.16 (Q6)
/6_7: D49.2 (A), U13.19 (Q7)
/7_0: D64.2 (A), U14.2 (Q0)
/7_1: D63.2 (A), U14.5 (Q1)
/7_2: D62.2 (A), U14.6 (Q2)
/7_3: D61.2 (A), U14.9 (Q3)
/7_4: D60.2 (A), U14.12 (Q4)
/7_5: D59.2 (A), U14.15 (Q5)
/7_6: D58.2 (A), U14.16 (Q6)
/7_7: D57.2 (A), U14.19 (Q7)
/BUS_0: J1.19, U7.3 (D0), U8.3 (D0), U9.3 (D0), U10.3 (D0), U11.3 (D0), U12.3 (D0), U13.3 (D0), U14.3 (D0)
/BUS_1: J1.18, U7.4 (D1), U8.4 (D1), U9.4 (D1), U10.4 (D1), U11.4 (D1), U12.4 (D1), U13.4 (D1), U14.4 (D1)
/BUS_2: J1.17, U7.7 (D2), U8.7 (D2), U9.7 (D2), U10.7 (D2), U11.7 (D2), U12.7 (D2), U13.7 (D2), U14.7 (D2)
/BUS_3: J1.16, U7.8 (D3), U8.8 (D3), U9.8 (D3), U10.8 (D3), U11.8 (D3), U12.8 (D3), U13.8 (D3), U14.8 (D3)
/BUS_4: J1.15, U7.13 (D4), U8.13 (D4), U9.13 (D4), U10.13 (D4), U11.13 (D4), U12.13 (D4), U13.13 (D4), U14.13 (D4)
/BUS_5: J1.14, U7.14 (D5), U8.14 (D5), U9.14 (D5), U10.14 (D5), U11.14 (D5), U12.14 (D5), U13.14 (D5), U14.14 (D5)
/BUS_6: J1.13, U7.17 (D6), U8.17 (D6), U9.17 (D6), U10.17 (D6), U11.17 (D6), U12.17 (D6), U13.17 (D6), U14.17 (D6)
/BUS_7: J1.12, U7.18 (D7), U8.18 (D7), U9.18 (D7), U10.18 (D7), U11.18 (D7), U12.18 (D7), U13.18 (D7), U14.18 (D7)
/CLK: J1.3, U1.5
GND: J1.36, J1.37, R1.1, R2.1, R3.1, R4.1, R5.1, R6.1, R7.1, R8.1, R9.1, R10.1, R11.1, R12.1, R13.1, R14.1, R15.1, R16.1, R17.1, R18.1, R19.1, R20.1, R21.1, R22.1, R23.1, R24.1, R25.1, R26.1, R27.1, R28.1, R29.1, R30.1, R31.1, R32.1, R33.1, R34.1, R35.1, R36.1, R37.1, R38.1, R39.1, R40.1, R41.1, R42.1, R43.1, R44.1, R45.1, R46.1, R47.1, R48.1, R49.1, R50.1, R51.1, R52.1, R53.1, R54.1, R55.1, R56.1, R57.1, R58.1, R59.1, R60.1, R61.1, R62.1, R63.1, R64.1, U1.7 (GND), U2.7 (GND), U3.7 (GND), U4.8 (GND), U7.10 (GND), U8.10 (GND), U9.10 (GND), U10.10 (GND), U11.10 (GND), U12.10 (GND), U13.10 (GND), U14.10 (GND)
unnamed: D1.1 (K), R1.2
unnamed: D2.1 (K), R2.2
unnamed: D3.1 (K), R3.2
unnamed: D4.1 (K), R4.2
unnamed: D5.1 (K), R5.2
unnamed: D6.1 (K), R6.2
unnamed: D7.1 (K), R7.2
unnamed: D8.1 (K), R8.2
unnamed: D9.1 (K), R9.2
unnamed: D10.1 (K), R10.2
unnamed: D11.1 (K), R11.2
unnamed: D12.1 (K), R12.2
unnamed: D13.1 (K), R13.2
unnamed: D14.1 (K), R14.2
unnamed: D15.1 (K), R15.2
unnamed: D16.1 (K), R16.2
unnamed: D17.1 (K), R17.2
unnamed: D18.1 (K), R18.2
unnamed: D19.1 (K), R19.2
unnamed: D20.1 (K), R20.2
unnamed: D21.1 (K), R21.2
unnamed: D22.1 (K), R22.2
unnamed: D23.1 (K), R23.2
unnamed: D24.1 (K), R24.2
unnamed: D25.1 (K), R25.2
unnamed: D26.1 (K), R26.2
unnamed: D27.1 (K), R27.2
unnamed: D28.1 (K), R28.2
unnamed: D29.1 (K), R29.2
unnamed: D30.1 (K), R30.2
unnamed: D31.1 (K), R31.2
unnamed: D32.1 (K), R32.2
unnamed: D33.1 (K), R33.2
unnamed: D34.1 (K), R34.2
unnamed: D35.1 (K), R35.2
unnamed: D36.1 (K), R36.2
unnamed: D37.1 (K), R37.2
unnamed: D38.1 (K), R38.2
unnamed: D39.1 (K), R39.2
unnamed: D40.1 (K), R40.2
unnamed: D41.1 (K), R41.2
unnamed: D42.1 (K), R42.2
unnamed: D43.1 (K), R43.2
unnamed: D44.1 (K), R44.2
unnamed: D45.1 (K), R45.2
unnamed: D46.1 (K), R46.2
unnamed: D47.1 (K), R47.2
unnamed: D48.1 (K), R48.2
unnamed: D49.1 (K), R49.2
unnamed: D50.1 (K), R50.2
unnamed: D51.1 (K), R51.2
unnamed: D52.1 (K), R52.2
unnamed: D53.1 (K), R53.2
unnamed: D54.1 (K), R54.2
unnamed: D55.1 (K), R55.2
unnamed: D56.1 (K), R56.2
unnamed: D57.1 (K), R57.2
unnamed: D58.1 (K), R58.2
unnamed: D59.1 (K), R59.2
unnamed: D60.1 (K), R60.2
unnamed: D61.1 (K), R61.2
unnamed: D62.1 (K), R62.2
unnamed: D63.1 (K), R63.2
unnamed: D64.1 (K), R64.2
unnamed: J1.1, U1.1
unnamed: J1.4, U1.3
unnamed: J1.8, SW1.1
unnamed: U1.6, U2.3, U2.6, U2.9, U2.12, U3.3, U3.6, U3.9, U3.12
unnamed: J1.11, U4.1 (A0)
unnamed: J1.10, U4.2 (A1)
unnamed: J1.9, U4.3 (A2)
unnamed: U1.4, U4.4 (E1)
unnamed: J1.7, U4.5 (E2)
unnamed: R65.1, SW1.2, U4.6 (E3)
unnamed: U3.2, U4.15 (O0)
unnamed: U3.5, U4.14 (O1)
unnamed: U3.8, U4.13 (O2)
unnamed: U3.11, U4.12 (O3)
unnamed: U2.2, U4.11 (O4)
unnamed: U2.5, U4.10 (O5)
unnamed: U2.8, U4.9 (O6)
unnamed: U2.11, U4.7 (O7)
unnamed: U3.1, U7.11 (Cp)
unnamed: U3.4, U8.11 (Cp)
unnamed: U3.10, U9.11 (Cp)
unnamed: U3.13, U10.11 (Cp)
unnamed: U1.2, U7.1 (~Mr), U8.1 (~Mr), U9.1 (~Mr), U10.1 (~Mr), U11.1 (~Mr), U12.1 (~Mr), U13.1 (~Mr), U14.1 (~Mr)
unnamed: U2.1, U11.11 (Cp)
unnamed: U2.4, U12.11 (Cp)
unnamed: U2.10, U13.11 (Cp)
unnamed: U2.13, U14.11 (Cp)

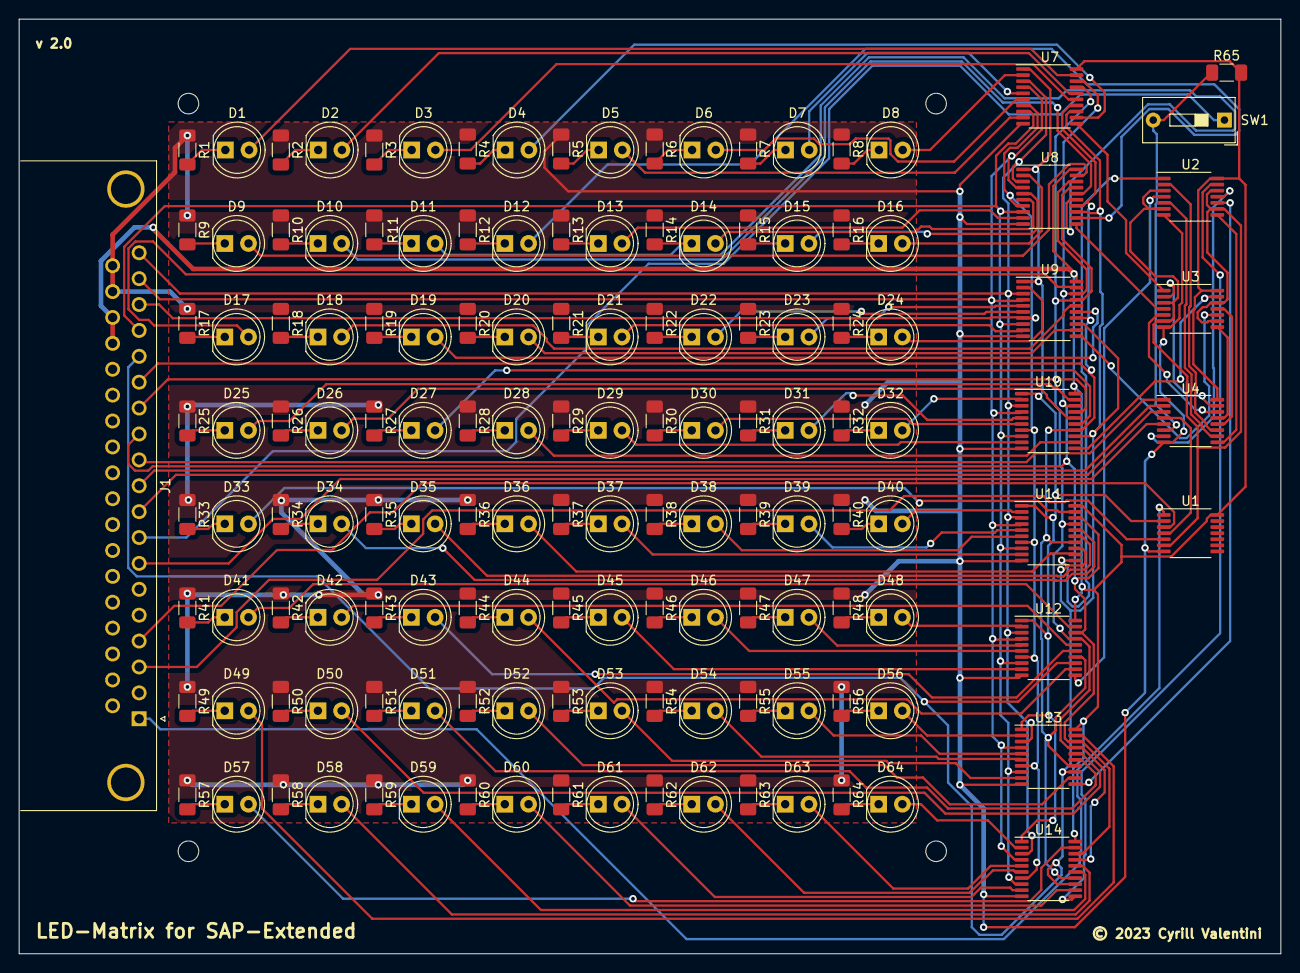
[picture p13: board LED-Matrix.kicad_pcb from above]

Board: 2 copper layers, 135.0 x 100.0 mm, 143 parts (0 on the bottom side), 166 nets.

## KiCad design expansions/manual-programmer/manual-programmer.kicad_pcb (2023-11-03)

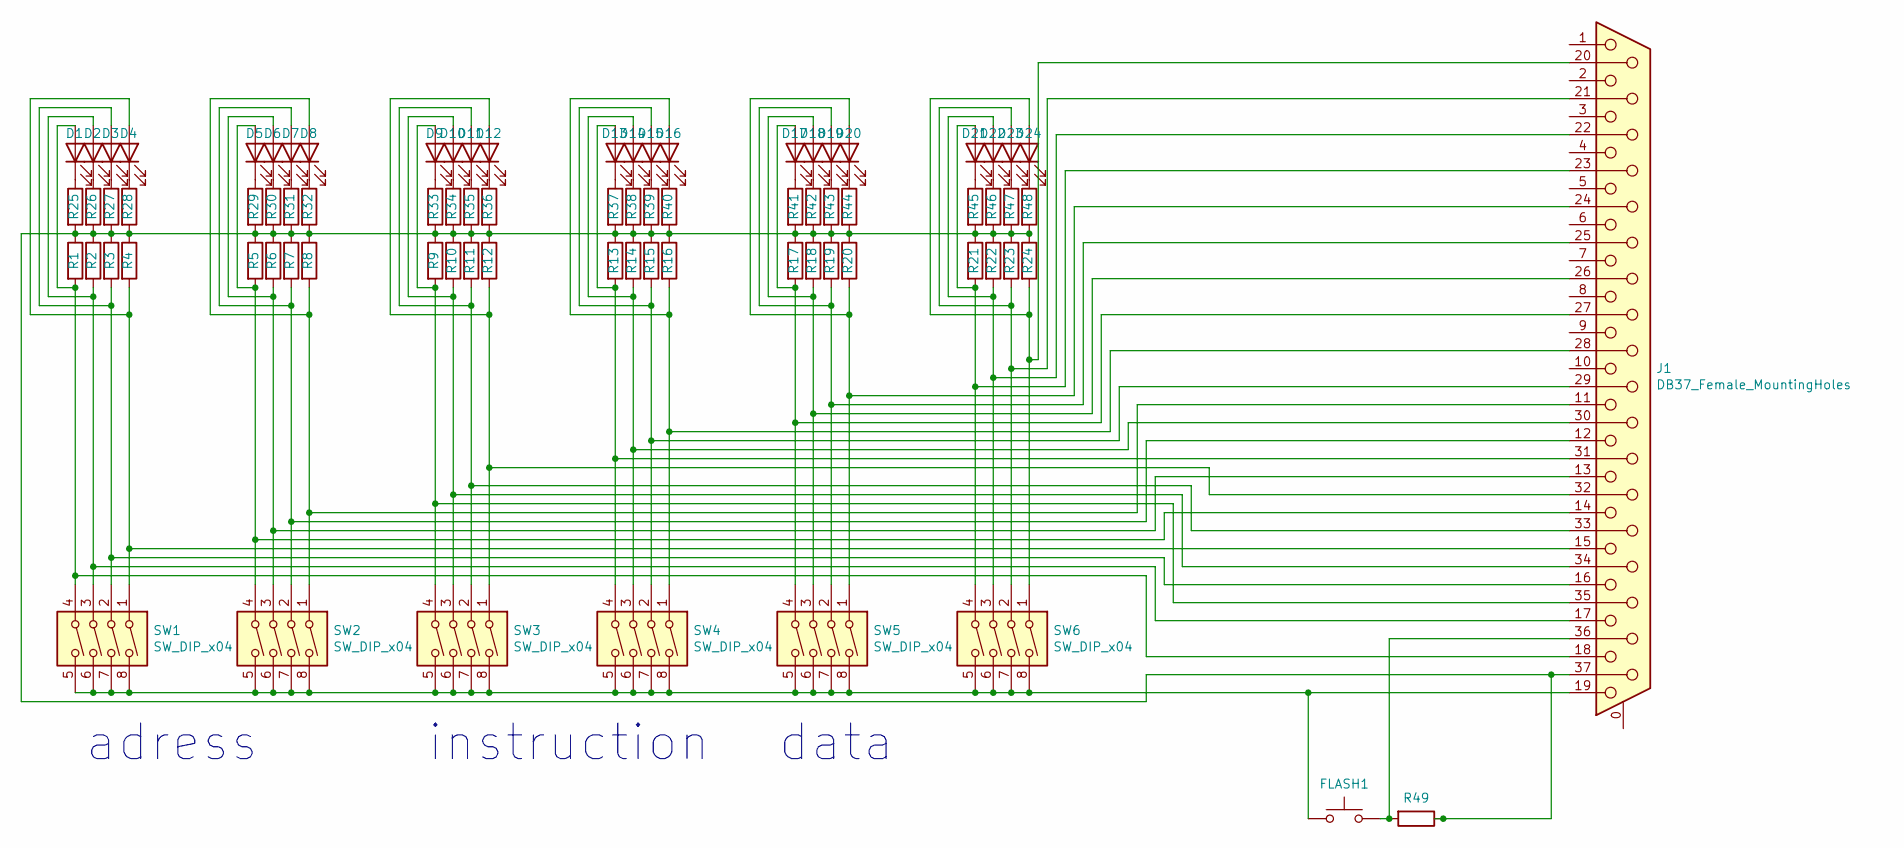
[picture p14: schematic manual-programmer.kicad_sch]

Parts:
D1, D2, D3, D4, D5, D6, D7, D8, D9, D10, D11, D12, D13, D14, D15, D16, D17, D18, D19, D20, D21, D22, D23, D24: LED; LED_D5.0mm
FLASH1: SW_Push; SW_PUSH_6mm
J1: DB37_Female_MountingHoles; DSUB-37_Female_Horizontal_P2.77x2.84mm_EdgePinOffset7.70mm_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
R1, R2, R3, R4, R5, R6, R7, R8, R9, R10, R11, R12, R13, R14, R15, R16, R17, R18, R19, R20, R21, R22, R23, R24: 10K; R_1206_3216Metric_Pad1.30x1.75mm_HandSolder
R25, R26, R27, R28, R29, R30, R31, R32, R33, R34, R35, R36, R37, R38, R39, R40, R41, R42, R43, R44, R45, R46, R47, R48: 470; R_1206_3216Metric_Pad1.30x1.75mm_HandSolder
R49: 1K; R_1206_3216Metric_Pad1.30x1.75mm_HandSolder
SW1, SW2, SW3, SW4, SW5, SW6: SW_DIP_x04; SW_DIP_SPSTx04_Slide_9.78x12.34mm_W7.62mm_P2.54mm

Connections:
unnamed: D1.2 (A), J1.18, R1.2, SW1.4
unnamed: D1.1 (K), R25.1
unnamed: D2.2 (A), J1.17, R2.2, SW1.3
unnamed: D2.1 (K), R26.1
unnamed: D3.2 (A), J1.16, R3.2, SW1.2
unnamed: D3.1 (K), R27.1
unnamed: D4.2 (A), J1.15, R4.2, SW1.1
unnamed: D4.1 (K), R28.1
unnamed: D5.2 (A), J1.14, R5.2, SW2.4
unnamed: D5.1 (K), R29.1
unnamed: D6.2 (A), J1.13, R6.2, SW2.3
unnamed: D6.1 (K), R30.1
unnamed: D7.2 (A), J1.12, R7.2, SW2.2
unnamed: D7.1 (K), R31.1
unnamed: D8.2 (A), J1.11, R8.2, SW2.1
unnamed: D8.1 (K), R32.1
unnamed: D9.2 (A), J1.35, R9.2, SW3.4
unnamed: D9.1 (K), R33.1
unnamed: D10.2 (A), J1.34, R10.2, SW3.3
unnamed: D10.1 (K), R34.1
unnamed: D11.2 (A), J1.33, R11.2, SW3.2
unnamed: D11.1 (K), R35.1
unnamed: D12.2 (A), J1.32, R12.2, SW3.1
unnamed: D12.1 (K), R36.1
unnamed: D13.2 (A), J1.31, R13.2, SW4.4
unnamed: D13.1 (K), R37.1
unnamed: D14.2 (A), J1.30, R14.2, SW4.3
unnamed: D14.1 (K), R38.1
unnamed: D15.2 (A), J1.29, R15.2, SW4.2
unnamed: D15.1 (K), R39.1
unnamed: D16.2 (A), J1.28, R16.2, SW4.1
unnamed: D16.1 (K), R40.1
unnamed: D17.2 (A), J1.27, R17.2, SW5.4
unnamed: D17.1 (K), R41.1
unnamed: D18.2 (A), J1.26, R18.2, SW5.3
unnamed: D18.1 (K), R42.1
unnamed: D19.2 (A), J1.25, R19.2, SW5.2
unnamed: D19.1 (K), R43.1
unnamed: D20.2 (A), J1.24, R20.2, SW5.1
unnamed: D20.1 (K), R44.1
unnamed: D21.2 (A), J1.23, R21.2, SW6.4
unnamed: D21.1 (K), R45.1
unnamed: D22.2 (A), J1.22, R22.2, SW6.3
unnamed: D22.1 (K), R46.1
unnamed: D23.2 (A), J1.21, R23.2, SW6.2
unnamed: D23.1 (K), R47.1
unnamed: D24.2 (A), J1.20, R24.2, SW6.1
unnamed: D24.1 (K), R48.1
unnamed: FLASH1.1, J1.19, SW1.5, SW1.6, SW1.7, SW1.8, SW2.5, SW2.6, SW2.7, SW2.8, SW3.5, SW3.6, SW3.7, SW3.8, SW4.5, SW4.6, SW4.7, SW4.8, SW5.5, SW5.6, SW5.7, SW5.8, SW6.5, SW6.6, SW6.7, SW6.8
unnamed: FLASH1.2, J1.36, R49.2
unnamed: J1.37, R1.1, R2.1, R3.1, R4.1, R5.1, R6.1, R7.1, R8.1, R9.1, R10.1, R11.1, R12.1, R13.1, R14.1, R15.1, R16.1, R17.1, R18.1, R19.1, R20.1, R21.1, R22.1, R23.1, R24.1, R25.2, R26.2, R27.2, R28.2, R29.2, R30.2, R31.2, R32.2, R33.2, R34.2, R35.2, R36.2, R37.2, R38.2, R39.2, R40.2, R41.2, R42.2, R43.2, R44.2, R45.2, R46.2, R47.2, R48.2, R49.1

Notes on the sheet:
adress
data
instruction

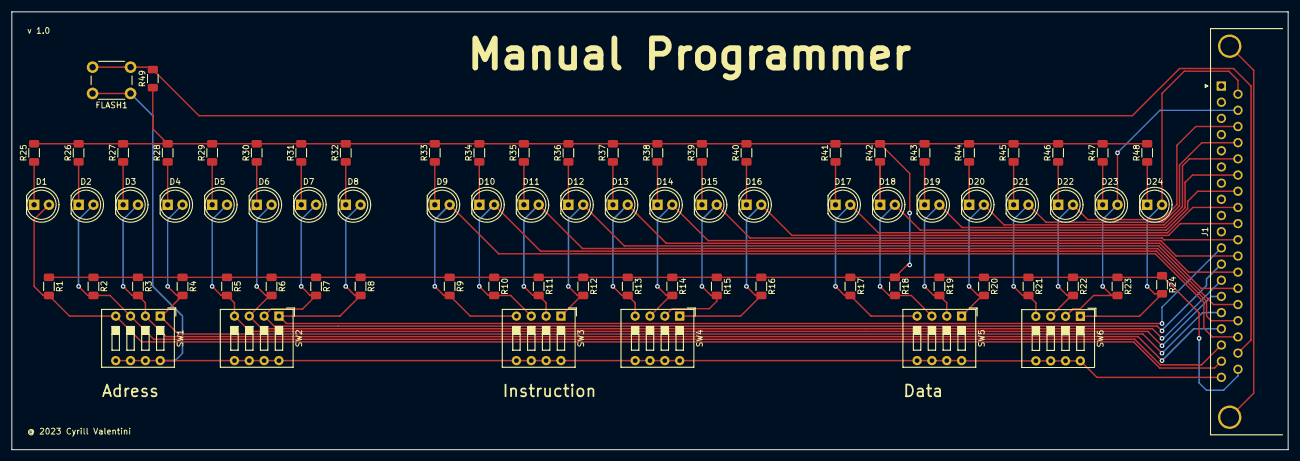
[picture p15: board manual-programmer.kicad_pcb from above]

Board: 2 copper layers, 218.4 x 74.9 mm, 81 parts (0 on the bottom side), 51 nets.

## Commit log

2023-11-03 uploading files, more cleanup needs to happen soon
    [7-Segment Cover v1.stl, 8-Bit Computer Rails v3 bottom.stl, 8-Bit Computer Rails v3 top.stl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]
2023-11-03 moved bom.html

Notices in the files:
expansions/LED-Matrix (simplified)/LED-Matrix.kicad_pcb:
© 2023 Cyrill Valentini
